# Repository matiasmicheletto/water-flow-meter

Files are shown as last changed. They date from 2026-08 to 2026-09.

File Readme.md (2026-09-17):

# Water Flow Meter (ESP32-CAM + YF-S401)

A wireless water flow monitoring system based on the YF-S401 Hall-effect flow sensor and the AI-Thinker ESP32-CAM board.

The system measures water flow by detecting the pulses generated by the Hall-effect sensor as water passes through the meter. The ESP32-CAM processes these pulses, calculates flow measurements, and provides a web-based interface for monitoring the system and its recorded data.

The device is designed for deployment in open-field environments where Internet connectivity may not be available. The ESP32-CAM operates as a standalone Wi-Fi Access Point (AP) and hosts the application directly on the device. A captive portal automatically presents the application when a user connects to the device's Wi-Fi network, allowing the flow meter to be configured and monitored from a phone, tablet, or computer without requiring Internet access, external network infrastructure, or cloud services.

The hardware uses an LM2596 DC-DC buck converter to regulate the input supply to the 5 V required by the ESP32-CAM. The device supports a 12 V input, allowing it to be powered from a compact 12 V battery or a vehicle/car battery, making it suitable for autonomous deployment in remote locations where conventional power sources may not be available.

## Hardware

The YF-S401 output signal is fed through a voltage divider built with 10 kΩ and 18 kΩ resistors to reduce the sensor signal to a level much closer to the 3.3 V logic range required by the ESP32-CAM input. The board also includes a small supply stabilization network on the main VCC rail: a 470 µF electrolytic capacitor and a 150 nF ceramic capacitor placed near the board input to absorb current spikes caused by the Wi-Fi radio and keep the voltage stable during transmission bursts.

| Component | Price (ARS-USD converted) | Est. US Market Price (USD) |
|---|---|---|
| ESP32-CAM + CH340G USB shield | $16.03 | $10.00 |
| Hall effect flow sensor (YF-S401) | $5.13 | $6.00 |
| 40-pin Dupont wire ribbon (30cm) | $4.49 | $3.00 |
| LM2596 DC-DC step-down power module | $3.21 | $2.00 |
| Class 4 Micro SDHC card | $3.21 | $4.00 |
| 70x90mm perfboard | $3.21 | $1.00 |
| 470uF electrolytic capacitor | $0.26 | $0.10 |
| 150nF polyester capacitor | $1.28 | $0.15 |
| 10k ohm 1/4W resistor | $0.19 | $0.05 |
| 18k ohm 1/4W resistor | $0.19 | $0.05 |
| 12V female DC power jack | $0.51 | $0.25 |
| 2.54mm jumper cap | $0.13 | $0.02 |
| 2.54mm female pin header | $0.96 | $0.50 |
| **Total Estimated Cost** | **$38.78** | **$27.12** |

<table>
	<tr>
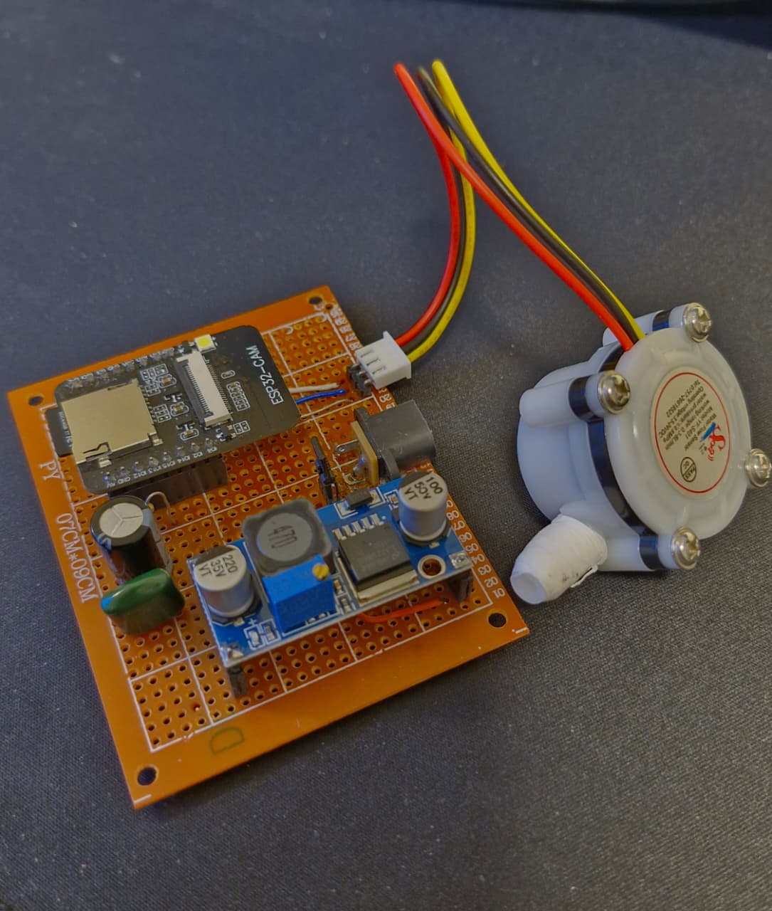
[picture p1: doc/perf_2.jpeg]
Perfboard 1
		<td></td>
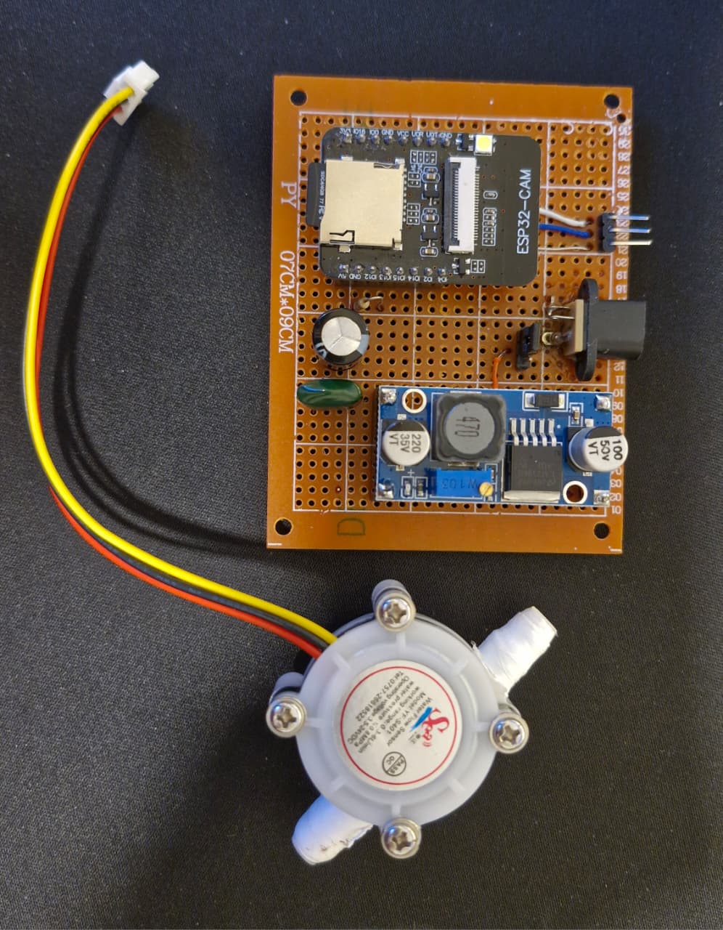
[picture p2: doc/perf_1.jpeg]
Perfboard 2
		<td></td>
	</tr>
</table> 

Notes:

- Flow sensor pulse pin: GPIO13 (`FLOW_SENSOR_PIN`)
- Storage: microSD card via `SD_MMC` in 1-bit mode
- Frontend storage: `LittleFS` (`data/index.html`)

### Schematic

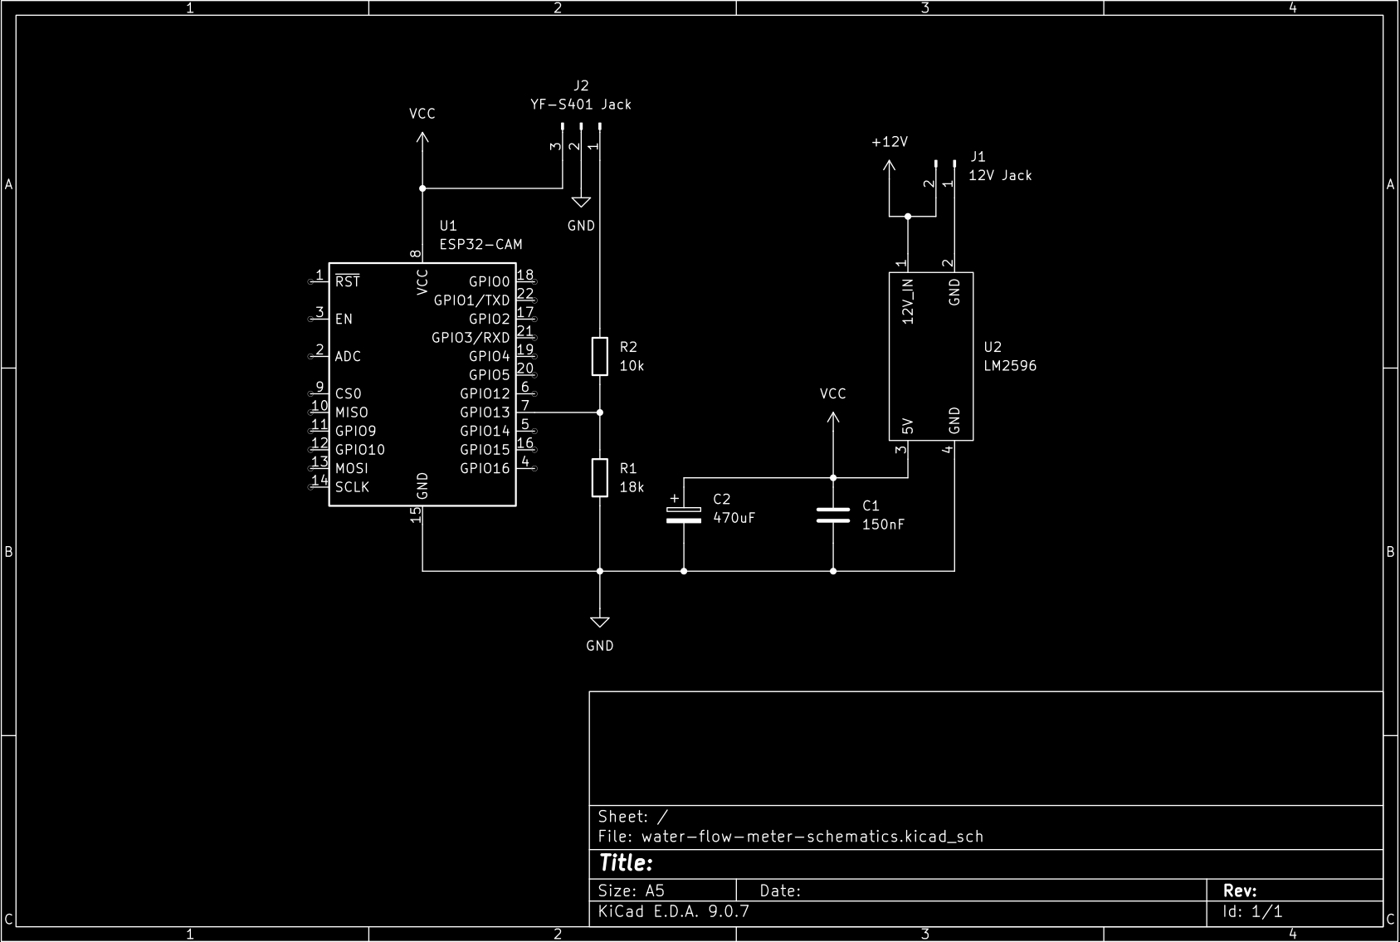
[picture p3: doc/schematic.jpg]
Circuit schematic


## Current firmware behavior

The firmware measures in fixed 1-second windows:

- `MEASUREMENT_INTERVAL_MS = 1000`
- `HISTORY_INTERVAL_MS = 1000`
- `FLUSH_INTERVAL_MS = 10000`
- `PULSES_PER_MINUTE_SCALE = 60000 / 1000 = 60`

Each sampling tick does the following:

1. Atomically read/reset the interrupt pulse counter.
2. Convert that 1-second pulse total into a flow rate:
   - `pulses_per_minute = pulse_count * 60`
3. Update cumulative `total_pulses`.
4. Store the sample in a RAM buffer and flush it to SD every 10 seconds.
5. Update the rolling live history used by the dashboard.

The CSV schema is still:

```csv
t_ms,pulse_count_10s,pulses_per_minute,total_pulses
```

The field name `pulse_count_10s` is retained for compatibility with the earlier version of the project, but in the current build it represents the pulses counted during the latest 1-second sample window.

Notes:

- Camera is intentionally not initialized so sensor/SD pin usage is preserved.
- Sensor input uses `INPUT_PULLUP` and interrupt on rising edge.
- If pulse noise causes overcounting, tune `MIN_PULSE_INTERVAL_US` in firmware.
- The AP is named `FlowMeter` with password `flowmeter123`.

## Interrupt-based pulse counting

- The ISR is intentionally minimal:
  - Reads `micros()`
  - Applies `MIN_PULSE_INTERVAL_US` debounce/noise filter
  - Increments a volatile pulse counter
- No heavy work, SD access, JSON generation, or serial writes happen in the ISR.

## SD logging and file handling

- A new log file is created every time the device boots, for example `/flow_log_0007.csv`.
- A persistent boot counter (`/boot_seq.txt`) tracks the next file index across reboots.
- Raw samples are buffered in RAM and flushed to SD every 10 seconds.
- `/api/files` lists all log files on SD, newest first, so the dashboard can offer a file picker.
- `/api/history` and `/api/export.csv` accept an optional `file` query parameter to inspect or export a previous session.
- The current session is served from the in-memory buffer and live-history state rather than re-reading the whole SD file on every poll.

## Dashboard behavior

The dashboard served from LittleFS provides three primary cards:

1. Current flow (`pulses/min`) from the latest completed 1-second sample.
2. Elapsed time since boot (`HH:MM:SS`).
3. Total pulses since boot, rendered with SI suffixes such as `k`, `M`, and `B`.

### GUI screenshot
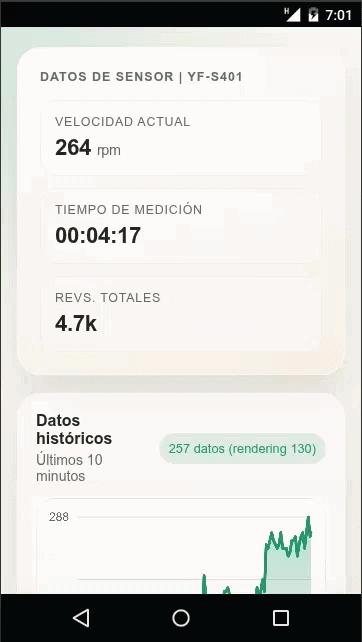
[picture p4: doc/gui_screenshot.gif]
GUI screenshot


Historical chart:

- X axis: elapsed time since reset `t_ms`
- Y axis: `pulses_per_minute`
- The live chart keeps a rolling 10-minute window for the current session
- Historical files are shown in full when selected from the dropdown
- Frontend-side deterministic subsampling preserves first/last points while reducing the number of rendered points on large histories

Polling behavior:

- Current metrics: every 1 second
- History: every 1 second
- File list refresh: every 15 seconds
- Elapsed time updates every second between polls for smoother UX

## API

### `GET /api/current`

Example:

```json
{
  "elapsed_ms": 123450,
  "pulse_count_10s": 15,
  "pulses_per_minute": 900,
  "total_pulses": 12345,
  "measurement_interval_ms": 1000,
  "has_measurement": true,
  "sd_ready": true,
  "current_file": "/flow_log_0007.csv"
}
```

### `GET /api/history`

The current implementation returns raw 1-second historical samples, not 10-second buckets.

Example:

```json
{
  "interval_ms": 1000,
  "measurement_interval_ms": 1000,
  "points": [
    { "t_ms": 1000, "pulses_per_minute": 60 },
    { "t_ms": 2000, "pulses_per_minute": 72 },
    { "t_ms": 3000, "pulses_per_minute": 84 }
  ]
}
```

This route accepts an optional `file` query parameter, for example:

```text
/api/history?file=/flow_log_0003.csv
```

When the current session is requested, the firmware uses a fast in-memory path. Historical files are replayed from SD when a previous log is selected.

### `GET /api/files`

Lists log files on SD, newest first:

```json
{
  "files": [
    { "name": "/flow_log_0007.csv", "current": true },
    { "name": "/flow_log_0006.csv", "current": false }
  ],
  "current": "/flow_log_0007.csv"
}
```

### `GET /api/export.csv`

Exports the full raw measurement history for the selected file or the current session.

```csv
t_ms,pulse_count_10s,pulses_per_minute,total_pulses
```

It accepts an optional `file` query parameter to export a specific log file instead of the active session.

## Running on hardware (PlatformIO)

Project config is `esp32cam` + Arduino framework + `115200` monitor/upload speed + LittleFS.

From the repository root:

1. Build firmware:

```bash
pio run
```

2. Upload firmware:

```bash
pio run --target upload --upload-port /dev/ttyUSB0
```

3. Upload the dashboard files to LittleFS:

```bash
pio run --target uploadfs --upload-port /dev/ttyUSB0
```

4. Open the serial monitor:

```bash
pio device monitor --port /dev/ttyUSB0 --baud 115200
```

5. If it is required to save output to a file use:

```bash
pio device monitor --port /dev/ttyUSB0 --baud 115200 --rts 0 --dtr 0 --filter esp32_exception_decoder --filter time --filter log2file
```

If upload fails, set the ESP32-CAM into flashing mode (IO0 to GND or hold the IO0 button as required by your adapter) and retry.

## Accessing the dashboard on device

- Connect to AP: `FlowMeter`
- Password: `flowmeter123`
- Open captive portal (or `http://10.0.0.1/`)

## Running the simulator

The simulator exposes the same API contract and serves the same dashboard UI.

From the repository root:

```bash
pip install -r requirements.txt
uvicorn simulator.main:app --reload
```

Open `http://127.0.0.1:8000/`.

Useful options:

- Start with long pre-generated history:

```bash
SIM_INITIAL_MINUTES=5000 uvicorn simulator.main:app --reload
```

- Reproducible randomness:

```bash
SIM_RANDOM_SEED=123 uvicorn simulator.main:app --reload
```

Simulation notes:

- Elapsed time continuously increases.
- Measurements are generated every 1 second.
- `pulses_per_minute` changes dynamically with noise and occasional shifts.
- The simulator exposes one synthetic log file (`/flow_log_sim.csv`) for API parity with the firmware.
- The dashboard and API behavior mirror the ESP32-CAM implementation closely, including file selection and CSV export.

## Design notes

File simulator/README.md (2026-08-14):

# Simulator

This FastAPI app simulates the ESP32 flow-meter API and serves the same dashboard UI from `data/index.html`.

## Run

From repository root:

```bash
pip install -r requirements.txt
uvicorn simulator.main:app --reload
```

Open `http://127.0.0.1:8000/`.

## API

- `GET /api/current`
- `GET /api/history`
- `GET /api/export.csv`

These routes match the firmware contract.

## Long-history testing

Set `SIM_INITIAL_MINUTES` before starting Uvicorn to start with pre-generated elapsed time/history.

Example:

```bash
SIM_INITIAL_MINUTES=5000 uvicorn simulator.main:app --reload
```

Optional deterministic randomness:

```bash
SIM_RANDOM_SEED=123 uvicorn simulator.main:app --reload
```

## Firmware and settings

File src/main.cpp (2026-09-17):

/*
 * Water flow meter - ESP32-CAM + YF-S401
 *
 * - Pulses are counted in an interrupt on GPIO13
 * - Every 10 seconds, pulses are sampled and converted to pulses/min
 * - 10-second records are buffered and persisted to SD
 * - Minute history is aggregated from six 10-second samples per minute
 * - AP mode serves a LittleFS-hosted dashboard + JSON/CSV APIs
 *
 * Camera is NOT initialized -> its pins are free for SD_MMC + sensor.
 *
 * --- async_tcp watchdog notes (read this before touching handlers) -------
 * Every server.on(...) lambda runs inside the "async_tcp" FreeRTOS task,
 * which is subscribed to the 5s task watchdog. Two rules follow from that,
 * and every handler below is written to respect them:
 *
 *   1. Never take a mutex with portMAX_DELAY from a handler. Always use a
 *      short pdMS_TO_TICKS() timeout and fail the request (503) if it
 *      expires. loop()-side code (sampleFlow, flushBufferToSD) is NOT in
 *      the watchdogged task, so it's fine for it to wait longer for the
 *      same locks.
 *   2. Never do unbounded work (reading a whole file into RAM, serializing
 *      under a lock that's also needed every second by loop()) inside a
 *      handler. Snapshot shared state under a short lock, release it, then
 *      do the slow part outside the lock; stream large payloads in bounded
 *      chunks instead of buffering them whole.
 */

#include <Arduino.h>
#include <WiFi.h>
#include <DNSServer.h>
#include <WebSerial.h>
#include <SD_MMC.h>
#include <LittleFS.h>
#include <ESPAsyncWebServer.h>
#include <ArduinoJson.h>
#include <vector>
#include <set>
#include <memory>
#include <algorithm>

// ---------- Pin assignments (AI-Thinker ESP32-CAM, camera disabled) ------
#define FLOW_SENSOR_PIN   13   // interrupt-capable, free when camera is off
// SD_MMC 1-bit mode uses fixed pins on ESP32-CAM: CLK=14, CMD=15, D0=2
// (D1/D2/D3 normally used by camera - we skip them by using 1-bit mode)

// ---------- Timing ---------------------------------------------------------
static const uint32_t MEASUREMENT_INTERVAL_MS = 1000;  // 1-second windows: raw sensor sampling rate
static const uint32_t HISTORY_INTERVAL_MS = 1000;      // 1 point per second: matches the sample rate so
                                                         // the chart and the current-reading card always
                                                         // show the exact same value at the exact same time
static const uint32_t FLUSH_INTERVAL_MS = 10000;       // persist every 10 seconds of samples
static const size_t BUFFER_CAPACITY = 24;               // ~24 seconds of 1s records (see FLUSH_INTERVAL_MS)

static const uint32_t HEAP_LOG_INTERVAL_MS = 30000;    // log heap status every 30 seconds
static uint32_t lastHeapLogMs = 0;

// These are derived from the two intervals above rather than hardcoded, so
// changing either interval can't silently desync the rpm card, the chart,
// and the CSV export from each other again. HISTORY_INTERVAL_MS must be an
// integer multiple of MEASUREMENT_INTERVAL_MS for the bucketing math below
// to line up; this is checked (and logged) once at boot in setup().
static const uint32_t PULSES_PER_MINUTE_SCALE = 60000 / MEASUREMENT_INTERVAL_MS;  // scales one raw
                                                                                    // sample's pulses to pulses/min
static const uint32_t SAMPLES_PER_HISTORY_POINT = HISTORY_INTERVAL_MS / MEASUREMENT_INTERVAL_MS; // raw
                                                                                    // samples folded into one chart point
static const uint32_t HISTORY_POINT_SCALE = 60000 / HISTORY_INTERVAL_MS;          // scales a finalized
                                                                                    // bucket's pulse sum to pulses/min

// The live in-RAM chart only needs a recent window, not the whole session
// (which stays fully available on SD for export regardless). Bounding
// minuteHistory to this many points keeps both its RAM footprint and the
// /api/history response size constant no matter how long the device runs.
static const uint32_t LIVE_WINDOW_MS = 10UL * 60UL * 1000UL; // 10 minutes
static const size_t MAX_HISTORY_POINTS = LIVE_WINDOW_MS / HISTORY_INTERVAL_MS;

// ---------- Mutex wait budgets ---------------------------------------------
// Handler-side waits (async_tcp task): short and bounded, see file header.
static const TickType_t HANDLER_LOCK_TIMEOUT = pdMS_TO_TICKS(100);
static const TickType_t HANDLER_SD_TIMEOUT   = pdMS_TO_TICKS(300);

// ---------- AP credentials ---------------------------------------------
static const char* AP_SSID = "FlowMeter";
static const char* AP_PASS = "flowmeter123"; // 8+ chars required by WiFi lib

// ---------- Captive portal ------------------------------------------------
// Resolves every DNS query to the AP IP so OS captive-portal probes (and any
// stray hostname lookups) land on this device instead of failing to resolve.
static const byte DNS_PORT = 53;
DNSServer dnsServer;

// ---------- Shared state between ISR and loop -----------------------------
volatile uint32_t pulseCount = 0;
volatile uint32_t lastPulseMicros = 0;

// Minimum time between counted pulses, in microseconds. Filters out noise/
// ringing that would otherwise be counted as real pulses. Tune this down if
// your real flow rate needs a higher max frequency than ~500 Hz allows;
// tune it up if you still see suspiciously flat/maxed-out readings.
static const uint32_t MIN_PULSE_INTERVAL_US = 2000; // caps at 500 Hz

void IRAM_ATTR onPulse() {
  uint32_t now = micros();
  // micros() wraps every ~71 min; this subtraction is wrap-safe.
  if ((uint32_t)(now - lastPulseMicros) >= MIN_PULSE_INTERVAL_US) {
    pulseCount++;
    lastPulseMicros = now;
  }
}

// Guards SD_MMC access shared between loop() (sampling/flush) and the
// AsyncTCP task (history/export handlers), which run concurrently.
SemaphoreHandle_t sdMutex;

// Guards the RAM record buffer (buffer/bufferLen) shared between loop()
// (sampling/flush) and the AsyncTCP task (history/export handlers).
SemaphoreHandle_t bufferMutex;

// Guards the incrementally-built minute history (minuteHistory + the live
// in-progress minute accumulator) shared between loop() (sampleFlow) and
// the AsyncTCP task (the /api/history handler's current-session fast path).
SemaphoreHandle_t historyMutex;

// ---------- Record buffer ---------------------------------------------
struct FlowRecord {
  uint32_t t_ms;             // elapsed since boot, recorded at end of 10s window
  uint32_t pulse_count_10s;  // pulses counted in this 10-second interval
  uint32_t pulses_per_minute;
  uint32_t total_pulses;     // cumulative pulses since boot
};

FlowRecord buffer[BUFFER_CAPACITY];
size_t bufferLen = 0;

// ---------- Incremental minute history (current session only) -----------
// Built up one finalized minute at a time as sampleFlow() runs, so
// /api/history can serve the current session without re-reading and
// re-parsing the whole SD log file on every poll. Historical files
// (requested via ?file=) still use the full-replay path since they're
// viewed rarely, not polled continuously.
struct MinutePoint {
  uint32_t t_ms;
  uint32_t pulses_per_minute;
};
std::vector<MinutePoint> minuteHistory;

bool minuteAccActive = false;
uint32_t minuteAccIndex = 0;
uint32_t minuteAccPulseSum = 0;
uint32_t minuteAccSampleCount = 0;

uint32_t totalPulses = 0;
uint32_t latestPulseCount10s = 0;
uint32_t latestPulsesPerMinute = 0;
uint32_t latestMeasurementElapsedMs = 0;
bool hasMeasurement = false;

uint32_t lastMeasurementMs = 0;
uint32_t lastFlushMs = 0;

bool sdReady = false;
// A fresh log file is created every boot (see initLogFile()); LOG_PATH
// always points at the file for the current session.
String LOG_PATH;
const char* BOOT_SEQ_PATH = "/boot_seq.txt";

// Real files present on LittleFS at boot, used to keep the static handler
// from swallowing every unmatched path (see buildAssetIndex()/setupServer()).
std::set<String> knownAssets;

AsyncWebServer server(80);

bool parseFlowRecordLine(const String &line, FlowRecord &record) {
  unsigned long tMs = 0;
  unsigned long pulseCount10s = 0;
  unsigned long pulsesPerMinute = 0;
  unsigned long totalPulsesParsed = 0;

  // Preferred schema: t_ms,pulse_count_10s,pulses_per_minute,total_pulses
  if (sscanf(line.c_str(), "%lu,%lu,%lu,%lu", &tMs, &pulseCount10s, &pulsesPerMinute, &totalPulsesParsed) == 4) {
    record.t_ms = static_cast<uint32_t>(tMs);
    record.pulse_count_10s = static_cast<uint32_t>(pulseCount10s);
    record.pulses_per_minute = static_cast<uint32_t>(pulsesPerMinute);
    record.total_pulses = static_cast<uint32_t>(totalPulsesParsed);
    return true;
  }

  // Backward-compatible parse for old schema: t_ms,pulses_sample,pulses_total_acc
  if (sscanf(line.c_str(), "%lu,%lu,%lu", &tMs, &pulseCount10s, &totalPulsesParsed) == 3) {
    record.t_ms = static_cast<uint32_t>(tMs);
    record.pulse_count_10s = static_cast<uint32_t>(pulseCount10s);
    record.pulses_per_minute = static_cast<uint32_t>(pulseCount10s * 6);
    record.total_pulses = static_cast<uint32_t>(totalPulsesParsed);
    return true;
  }

  return false;
}

// Only accepts paths this firmware itself could have generated, so the
// "file" query param can never be used to open arbitrary SD paths.
bool isValidLogFile(const String &path) {
  static const char *PREFIX = "/flow_log_";
  static const char *SUFFIX = ".csv";
  size_t prefixLen = strlen(PREFIX);
  size_t suffixLen = strlen(SUFFIX);

  if (path.length() <= prefixLen + suffixLen) return false;
  if (!path.startsWith(PREFIX) || !path.endsWith(SUFFIX)) return false;

  String middle = path.substring(prefixLen, path.length() - suffixLen);
  if (middle.length() == 0) return false;
  for (size_t i = 0; i < middle.length(); i++) {
    if (!isDigit(middle[i])) return false;
  }
  return true;
}

// ---------- SD helpers ---------------------------------------------------
// Reads/increments a persistent boot counter and returns a unique log path
// for this session, e.g. "/flow_log_0007.csv". Must be called with sdMutex
// already held or before the server/loop start touching SD.
String allocateLogPath() {
  unsigned long seq = 0;
  if (SD_MMC.exists(BOOT_SEQ_PATH)) {
    File f = SD_MMC.open(BOOT_SEQ_PATH, FILE_READ);
    if (f) {
      seq = f.parseInt();
      f.close();
    }
  }

  File f = SD_MMC.open(BOOT_SEQ_PATH, FILE_WRITE);
  if (f) {
    f.print(seq + 1);
    f.close();
  }

  char path[32];
  snprintf(path, sizeof(path), "/flow_log_%04lu.csv", seq);
  return String(path);
}

// setup()-only: runs once before the server or loop() ever touch SD, so a
// generous wait here is fine - there's no contention yet and nothing is
// watchdogged at this point.
void ensureLogHeader() {
  if (xSemaphoreTake(sdMutex, pdMS_TO_TICKS(2000)) != pdTRUE) {
    Serial.println("[SD] log header skipped, sdMutex busy");
    WebSerial.println("[SD] log header skipped, sdMutex busy");
    return;
  }
  if (!SD_MMC.exists(LOG_PATH)) {
    File f = SD_MMC.open(LOG_PATH, FILE_WRITE);
    if (f) {
      f.println("t_ms,pulse_count_10s,pulses_per_minute,total_pulses");
      f.close();
    }
  }
  xSemaphoreGive(sdMutex);
}

// Creates a brand-new log file for this boot session, so past runs are
// preserved as separate files instead of being appended to. setup()-only,
// same reasoning as ensureLogHeader() above.
void initLogFile() {
  if (xSemaphoreTake(sdMutex, pdMS_TO_TICKS(2000)) != pdTRUE) {
    Serial.println("[SD] log init skipped, sdMutex busy");
    WebSerial.println("[SD] log init skipped, sdMutex busy");
    return;
  }
  LOG_PATH = allocateLogPath();
  xSemaphoreGive(sdMutex);
  ensureLogHeader();
}

// Lists log files on SD (newest first), for the export file picker. Called
// from the /api/files handler, i.e. from the async_tcp task - bounded wait.
bool listLogFiles(std::vector<String> &names) {
  if (xSemaphoreTake(sdMutex, HANDLER_SD_TIMEOUT) != pdTRUE) {
    return false;
  }
  File root = SD_MMC.open("/");
  if (root) {
    File entry = root.openNextFile();
    while (entry) {
      String name = String(entry.name());
      if (!name.startsWith("/")) {
        name = "/" + name;
      }
      if (name.startsWith("/flow_log_") && name.endsWith(".csv")) {
        names.push_back(name);
      }
      entry = root.openNextFile();
    }
    root.close();
  }
  xSemaphoreGive(sdMutex);

  std::sort(names.begin(), names.end(), std::greater<String>());
  return true;
}

// loop()-only (not the watchdogged async_tcp task), so waiting for the
// locks here can afford to be generous - the readers on the handler side
// now hold them only briefly, so contention windows are short anyway.
void flushBufferToSD() {
  if (!sdReady) return;

  // Snapshot under the buffer lock, then release it before touching SD so
  // concurrent /api/history and /api/export.csv reads are never blocked by
  // slow SD I/O.
  FlowRecord snapshot[BUFFER_CAPACITY];
  size_t snapshotLen;

  xSemaphoreTake(bufferMutex, portMAX_DELAY);
  snapshotLen = bufferLen;
  memcpy(snapshot, buffer, sizeof(FlowRecord) * snapshotLen);
  xSemaphoreGive(bufferMutex);

  if (snapshotLen == 0) return;

  if (xSemaphoreTake(sdMutex, pdMS_TO_TICKS(2000)) != pdTRUE) {
    Serial.println("[SD] flush skipped, sdMutex busy");
    WebSerial.println("[SD] flush skipped, sdMutex busy");
    return;
  }
  File f = SD_MMC.open(LOG_PATH, FILE_APPEND);
  if (!f) {
    xSemaphoreGive(sdMutex);
    Serial.println("[SD] failed to open log for append");
    WebSerial.println("[SD] failed to open log for append");
    return;
  }
  for (size_t i = 0; i < snapshotLen; i++) {
    f.printf("%lu,%lu,%lu,%lu\n",
             snapshot[i].t_ms,
             snapshot[i].pulse_count_10s,
             snapshot[i].pulses_per_minute,
             snapshot[i].total_pulses);
  }
  f.close();
  xSemaphoreGive(sdMutex);

  // Only drop the records we actually persisted; anything appended while we
  // were writing to SD (e.g. sampleFlow's buffer-full retry) stays queued.
  xSemaphoreTake(bufferMutex, portMAX_DELAY);
  if (bufferLen >= snapshotLen) {
    memmove(buffer, buffer + snapshotLen, sizeof(FlowRecord) * (bufferLen - snapshotLen));
    bufferLen -= snapshotLen;
  }
  xSemaphoreGive(bufferMutex);

  Serial.printf("[SD] flushed %u records\n", (unsigned)snapshotLen);
  WebSerial.printf("[SD] flushed %u records\n", (unsigned)snapshotLen);
}

// ---------- Sensor sampling (loop()-only) --------------------------------
void sampleFlow(uint32_t measurementElapsedMs) {
  noInterrupts();
  uint32_t pulses = pulseCount;
  pulseCount = 0;
  interrupts();

  uint32_t pulsesPerMinute = pulses * PULSES_PER_MINUTE_SCALE;

  totalPulses += pulses;
  latestPulseCount10s = pulses;
  latestPulsesPerMinute = pulsesPerMinute;
  latestMeasurementElapsedMs = measurementElapsedMs;
  hasMeasurement = true;

  FlowRecord record;
  record.t_ms = measurementElapsedMs;
  record.pulse_count_10s = pulses;
  record.pulses_per_minute = pulsesPerMinute;
  record.total_pulses = totalPulses;

  xSemaphoreTake(bufferMutex, portMAX_DELAY);
  bool bufferFull = (bufferLen >= BUFFER_CAPACITY);
  if (!bufferFull) {
    buffer[bufferLen++] = record;
  }
  xSemaphoreGive(bufferMutex);

  if (bufferFull) {
    // buffer full before scheduled flush - flush now to avoid losing data
    flushBufferToSD();
    xSemaphoreTake(bufferMutex, portMAX_DELAY);
    if (bufferLen < BUFFER_CAPACITY) {
      buffer[bufferLen++] = record;
    }
    xSemaphoreGive(bufferMutex);
  }

  // Fold this sample into the current history bucket, finalizing it the
  // moment enough samples have accumulated (rather than waiting for the
  // next sample to prove the bucket is over) so the chart's newest point
  // shows up in the same tick as the rpm card, not a bucket later.
  xSemaphoreTake(historyMutex, portMAX_DELAY);
  if (!minuteAccActive) {
    minuteAccActive = true;
    minuteAccIndex = (measurementElapsedMs - 1) / HISTORY_INTERVAL_MS;
  }
  minuteAccPulseSum += pulses;
  minuteAccSampleCount++;

  if (minuteAccSampleCount >= SAMPLES_PER_HISTORY_POINT) {
    MinutePoint point;
    point.t_ms = (minuteAccIndex + 1) * HISTORY_INTERVAL_MS;
    point.pulses_per_minute = minuteAccPulseSum * HISTORY_POINT_SCALE;
    minuteHistory.push_back(point);
    // Bounded to a rolling window (~600 points at 1/sec for 10 minutes) -
    // one erase-from-front per second is negligible work on this hardware,
    // and it's far simpler than a manual circular-buffer index for a
    // vector this small.
    if (minuteHistory.size() > MAX_HISTORY_POINTS) {
      minuteHistory.erase(minuteHistory.begin());
    }
    minuteAccActive = false;
    minuteAccPulseSum = 0;
    minuteAccSampleCount = 0;
  }
  xSemaphoreGive(historyMutex);
}

// ---------- Static-asset filtering -----------------------------------------
// Walks LittleFS once at boot and records every real file. serveStatic()'s
// filter then only matches requests against this set (plus "/"), instead of
// matching every non-/api/ path. Without this, serveStatic's broad filter
// claims requests like /generate_204 or /favicon.ico before they ever reach
// the captive-portal redirect in onNotFound() - each one then falls through
// AsyncStaticWebHandler's internal "try .gz, then plain, then index.html"
// fallback, doing several synchronous flash reads per bogus request, all
// inside the watchdogged async_tcp task. A burst of these around Wi-Fi
// association is exactly what was tripping the task watchdog.
void buildAssetIndex() {
  File root = LittleFS.open("/");
  if (!root) return;
  File f = root.openNextFile();
  while (f) {
    if (!f.isDirectory()) {
      String name = String(f.name());
      if (!name.startsWith("/")) {
        name = "/" + name;
      }
      knownAssets.insert(name);
    }
    f = root.openNextFile();
  }
  root.close();
  Serial.printf("[LittleFS] indexed %u asset(s)\n", (unsigned)knownAssets.size());
}

// ---------- CSV export state (async_tcp task, streamed) -------------------
// Carried by shared_ptr into the chunked-response callback so it lives
// exactly as long as the response does and is freed automatically when it
// finishes - no manual cleanup path to get wrong on the error branches.
struct ExportState {
  File file;
  bool fileOpen = false;
  bool headerPending = false;
  bool includeBuffer = false;
  bool bufferDone = false;
  FlowRecord bufSnapshot[BUFFER_CAPACITY];
  size_t bufLen = 0;
  size_t bufIndex = 0;
};
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
void loop() {
  WebSerial.loop();
  dnsServer.processNextRequest(); // lightweight, non-blocking DNS capture

  uint32_t now = millis();

  // Log heap status periodically.
  if (now - lastHeapLogMs >= HEAP_LOG_INTERVAL_MS) {
    lastHeapLogMs = now;
    Serial.printf("[HEAP] free=%u largest=%u minfree=%u\n",ESP.getFreeHeap(), ESP.getMaxAllocHeap(), ESP.getMinFreeHeap());
  }

  // Perform any other periodic tasks here.
  while ((uint32_t)(now - lastMeasurementMs) >= MEASUREMENT_INTERVAL_MS) {
    lastMeasurementMs += MEASUREMENT_INTERVAL_MS;
    sampleFlow(lastMeasurementMs);
  }

  // Flush any remaining data to the SD card periodically.
  if (now - lastFlushMs >= FLUSH_INTERVAL_MS) {
    lastFlushMs = now;
    flushBufferToSD();
  }

  delay(1); // Short delay to yield to other tasks and avoid watchdog resets.
}

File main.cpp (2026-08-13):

/*
 * Water flow meter - ESP32-CAM + YF-S401
 * Step 1: sensor sampling (1s) + buffered SD logging (flush ~60s)
 *         + AP mode + web server serving LittleFS index.html
 *         + /api/current JSON endpoint (polled by the page)
 *
 * Camera is NOT initialized -> its pins are free for SD_MMC + sensor.
 */

#include <Arduino.h>
#include <WiFi.h>
#include <SD_MMC.h>
#include <LittleFS.h>
#include <ESPAsyncWebServer.h>
#include <ArduinoJson.h>

// ---------- Pin assignments (AI-Thinker ESP32-CAM, camera disabled) ------
#define FLOW_SENSOR_PIN   13   // interrupt-capable, free when camera is off
// SD_MMC 1-bit mode uses fixed pins on ESP32-CAM: CLK=14, CMD=15, D0=2
// (D1/D2/D3 normally used by camera - we skip them by using 1-bit mode)

// ---------- Flow sensor calibration --------------------------------------
// YF-S401: verify this constant against your specific unit's datasheet.
// Commonly cited around 5880 pulses/L for the small-bore YF-S401 (~98 Hz per L/min).
// CHANGE THIS to match your sensor's actual calibration sheet.
static const float PULSES_PER_LITER = 5880.0f;

// ---------- Timing ---------------------------------------------------------
static const uint32_t SAMPLE_INTERVAL_MS = 1000;   // measure every 1s
static const uint32_t FLUSH_INTERVAL_MS  = 60000;  // dump to SD every ~60s
static const size_t   BUFFER_CAPACITY    = 70;      // ~70s of margin before flush

// ---------- AP credentials ---------------------------------------------
static const char* AP_SSID = "FlowMeter";
static const char* AP_PASS = "flowmeter123"; // 8+ chars required by WiFi lib

// ---------- Shared state between ISR and loop -----------------------------
volatile uint32_t pulseCount = 0;

void IRAM_ATTR onPulse() {
  pulseCount++;
}

// ---------- Record buffer ---------------------------------------------
struct FlowRecord {
  uint32_t t_ms;       // millis() at time of sample (relative timestamp)
  float    flow_lpm;   // instantaneous flow, liters/minute
  float    liters_acc; // cumulative liters since boot
};

FlowRecord buffer[BUFFER_CAPACITY];
size_t bufferLen = 0;

float totalLiters = 0.0f;
float currentFlowLpm = 0.0f;   // latest reading, exposed via /api/current
uint32_t currentSampleTime = 0;

uint32_t lastSampleMs = 0;
uint32_t lastFlushMs = 0;

bool sdReady = false;
const char* LOG_PATH = "/flow_log.csv";

AsyncWebServer server(80);

// ---------- SD helpers ---------------------------------------------------
void ensureLogHeader() {
  if (!SD_MMC.exists(LOG_PATH)) {
    File f = SD_MMC.open(LOG_PATH, FILE_WRITE);
    if (f) {
      f.println("t_ms,flow_lpm,liters_acc");
      f.close();
    }
  }
}

void flushBufferToSD() {
  if (!sdReady || bufferLen == 0) return;

  File f = SD_MMC.open(LOG_PATH, FILE_APPEND);
  if (!f) {
    Serial.println("[SD] failed to open log for append");
    return;
  }
  for (size_t i = 0; i < bufferLen; i++) {
    f.printf("%lu,%.3f,%.3f\n",
             buffer[i].t_ms, buffer[i].flow_lpm, buffer[i].liters_acc);
  }
  f.close();
  Serial.printf("[SD] flushed %u records\n", (unsigned)bufferLen);
  bufferLen = 0;
}

// ---------- Sensor sampling ---------------------------------------------
void sampleFlow() {
  noInterrupts();
  uint32_t pulses = pulseCount;
  pulseCount = 0;
  interrupts();

  // pulses in this 1s window -> instantaneous flow rate (L/min)
  float litersThisSample = pulses / PULSES_PER_LITER;
  float flow_lpm = litersThisSample * 60.0f; // 1s window -> scale to per-minute

  totalLiters += litersThisSample;
  currentFlowLpm = flow_lpm;
  currentSampleTime = millis();

  if (bufferLen < BUFFER_CAPACITY) {
    buffer[bufferLen].t_ms = currentSampleTime;
    buffer[bufferLen].flow_lpm = flow_lpm;
    buffer[bufferLen].liters_acc = totalLiters;
    bufferLen++;
  } else {
    // buffer full before scheduled flush - flush now to avoid losing data
    flushBufferToSD();
    buffer[bufferLen].t_ms = currentSampleTime;
    buffer[bufferLen].flow_lpm = flow_lpm;
    buffer[bufferLen].liters_acc = totalLiters;
    bufferLen++;
  }
}

// ---------- Web server routes --------------------------------------------
void setupServer() {
  if (!LittleFS.begin(true)) {
    Serial.println("[LittleFS] mount failed");
  }

  // Serve the frontend from LittleFS (data/index.html -> uploaded via
  // `pio run --target uploadfs`), fully decoupled from firmware logic.
  server.serveStatic("/", LittleFS, "/").setDefaultFile("index.html");

  // Current reading, polled by the page every second.
  server.on("/api/current", HTTP_GET, [](AsyncWebServerRequest *request) {
    JsonDocument doc;
    doc["t_ms"] = currentSampleTime;
    doc["flow_lpm"] = currentFlowLpm;
    doc["liters_acc"] = totalLiters;
    doc["buffered"] = bufferLen;
    doc["sd_ready"] = sdReady;

    String out;
    serializeJson(doc, out);
    request->send(200, "application/json", out);
  });

  server.begin();
}

// ---------- Setup / loop --------------------------------------------------
void setup() {
  Serial.begin(115200);
  delay(200);

  pinMode(FLOW_SENSOR_PIN, INPUT_PULLUP);
  attachInterrupt(digitalPinToInterrupt(FLOW_SENSOR_PIN), onPulse, RISING);

  // SD in 1-bit mode: frees D1/D2/D3 lines that camera would otherwise use.
  if (SD_MMC.begin("/sdcard", true)) {
    sdReady = true;
    ensureLogHeader();
    Serial.println("[SD] mounted ok (1-bit mode)");
  } else {
    Serial.println("[SD] mount failed - logging disabled, AP+API still work");
  }

  WiFi.mode(WIFI_AP);
  WiFi.softAP(AP_SSID, AP_PASS);
  Serial.print("[AP] started, IP: ");
  Serial.println(WiFi.softAPIP());

  setupServer();

  lastSampleMs = millis();
  lastFlushMs = millis();
}

void loop() {
  uint32_t now = millis();

  if (now - lastSampleMs >= SAMPLE_INTERVAL_MS) {
    lastSampleMs = now;
    sampleFlow();
  }

  if (now - lastFlushMs >= FLUSH_INTERVAL_MS) {
    lastFlushMs = now;
    flushBufferToSD();
  }
}

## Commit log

2026-08-14 Refactored dashboard to display values in pulses/minute. Improved history chart. ESP32 board simulator with python API to test front-end
2026-09-14 Firmware (main.cpp):
    - Each boot creates a new log file (/flow_log_NNNN.csv), tracked via a persistent counter (/boot_seq.txt) so past sessions are never overwritten.
    - FLUSH_INTERVAL_MS changed from 60s to 10s so buffered records hit SD every 10 seconds.
    - Added /api/files (lists all log files, newest first, flags the current one).
    - /api/history and /api/export.csv now accept an optional ?file= param to target a specific past log file; the in-memory buffer is only merged in when the current session's file is selected.
    - /api/current now reports current_file.
    Simulator (main.py): mirrors the new current_file//api/files/file query-param contract for dev parity.
    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
2026-09-15 - Captive portal — unchanged, exactly as before (DNSServer, port 53 wildcard resolution, processNextRequest() in loop(), all six detection routes redirecting to /). - onNotFound — now checks request-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
    [main.cpp]
2026-09-15 Fixed API+frontend+firmware requirement to update data every one second. Minor front end style changes
    [main.cpp]
2026-09-16 Kicad schematic and documentation
    [water-flow-meter-schematics.kicad_pcb, water-flow-meter-schematics.kicad_sch]
2026-09-16 fix: bound handler-side locks, stream CSV export, fix captive portal routing Root causes of the async_tcp task watchdog abort on client connect/reconnect: - /api/history and /api/export.csv took hist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
    [main.cpp]
2026-09-17 - add explicit captive-portal probe redirects for Android, iOS/macOS, and Windows endpoints - expand hardware documentation with voltage-divider and VCC stabilization details - add BOM and cost break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
